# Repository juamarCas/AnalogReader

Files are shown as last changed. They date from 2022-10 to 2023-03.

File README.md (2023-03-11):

# Analog Reader
Circuit board based on STM303RBT6 microcontroller, made using Kicad v6

## Footage

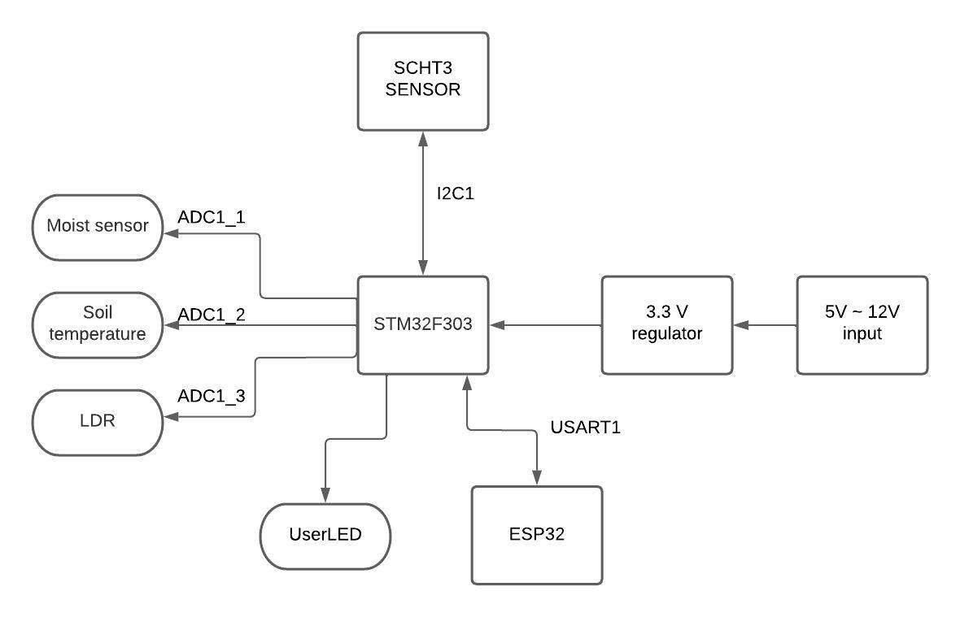
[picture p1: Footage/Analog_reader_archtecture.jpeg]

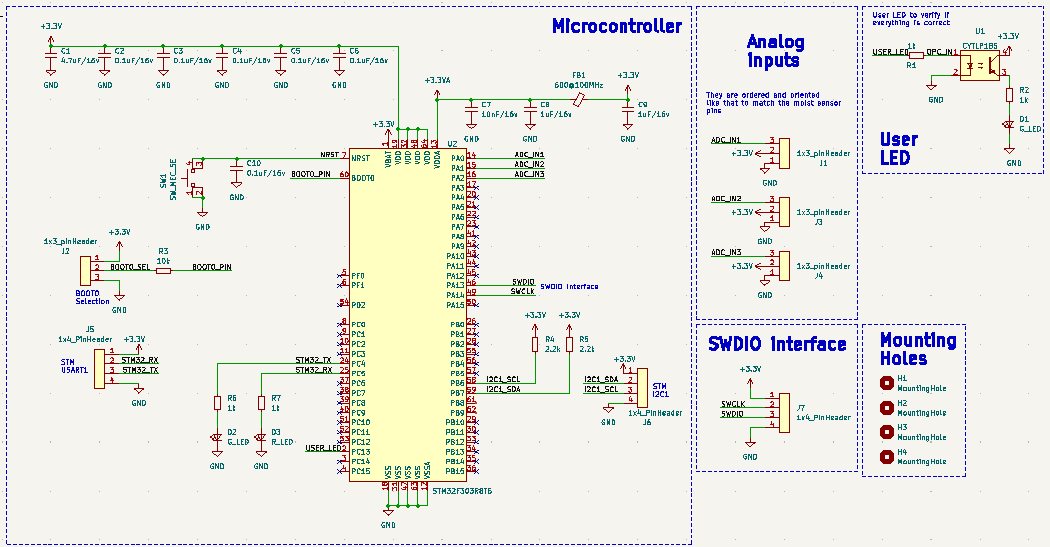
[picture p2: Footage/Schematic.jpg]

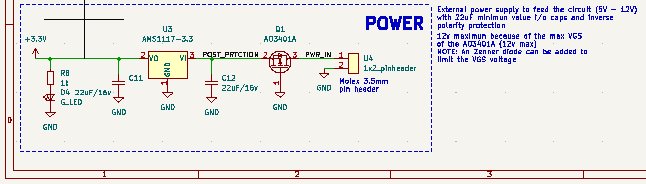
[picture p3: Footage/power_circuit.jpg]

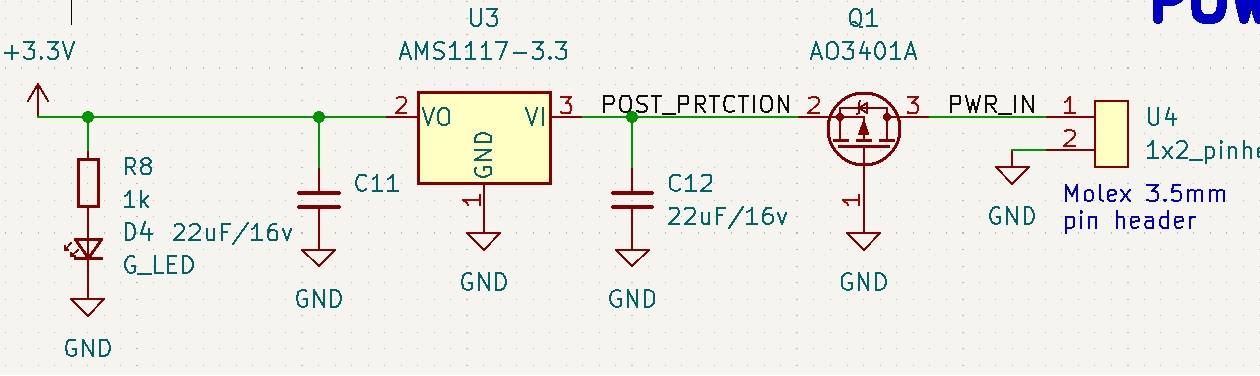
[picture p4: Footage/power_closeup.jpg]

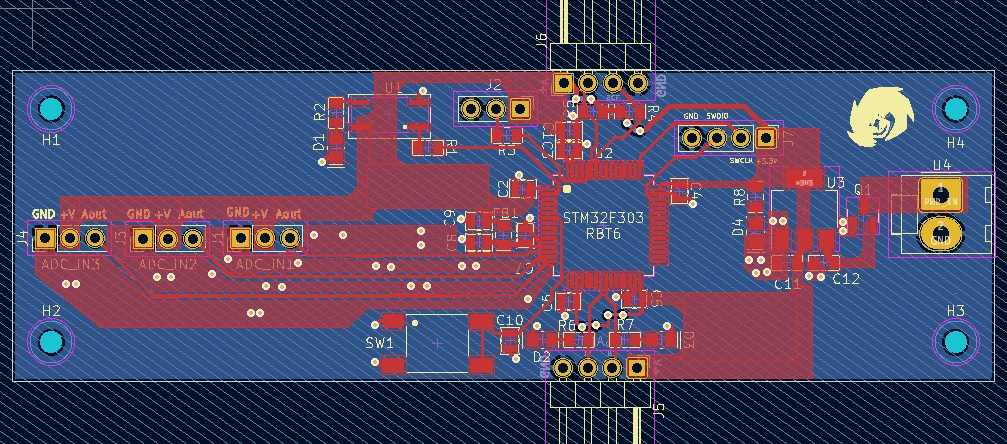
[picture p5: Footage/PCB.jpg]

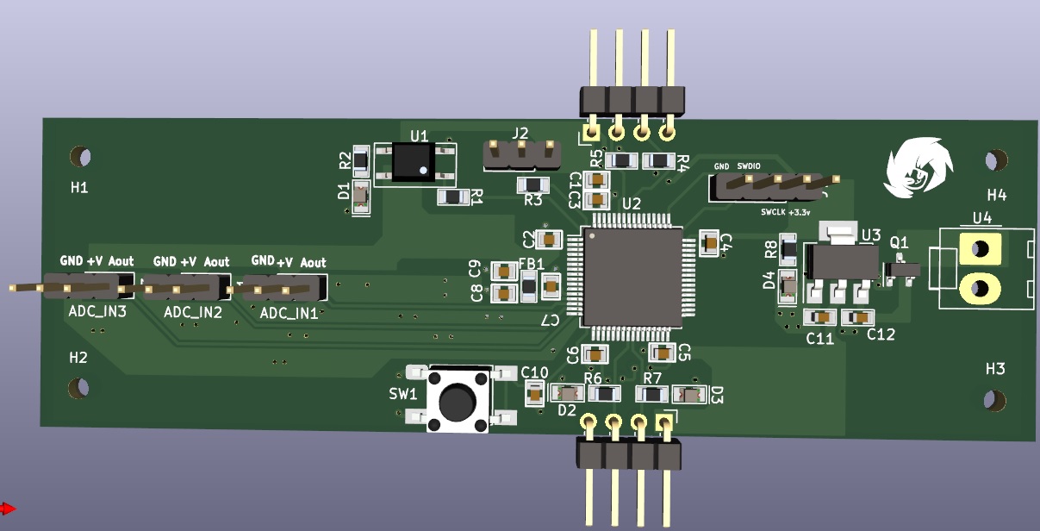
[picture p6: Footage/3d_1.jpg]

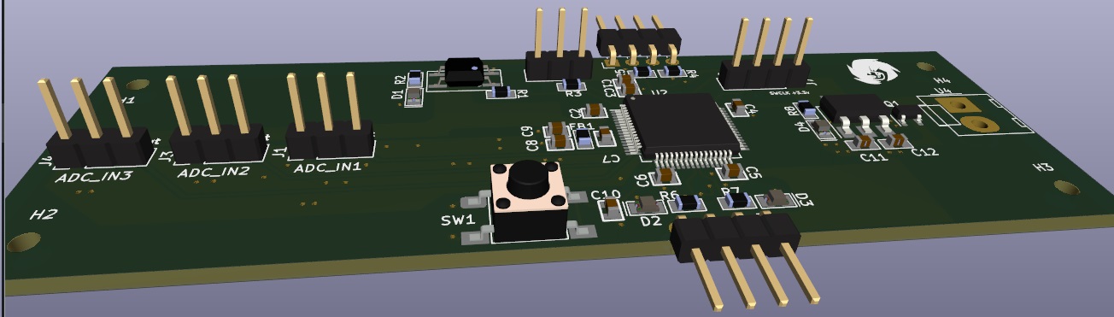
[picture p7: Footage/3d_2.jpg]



## Other parts of the project
* [MQTT Middleware](https://github.com/juamarCas/MQTT_middleware)
* [API REST](https://github.com/juamarCas/Sensor_API_REST)

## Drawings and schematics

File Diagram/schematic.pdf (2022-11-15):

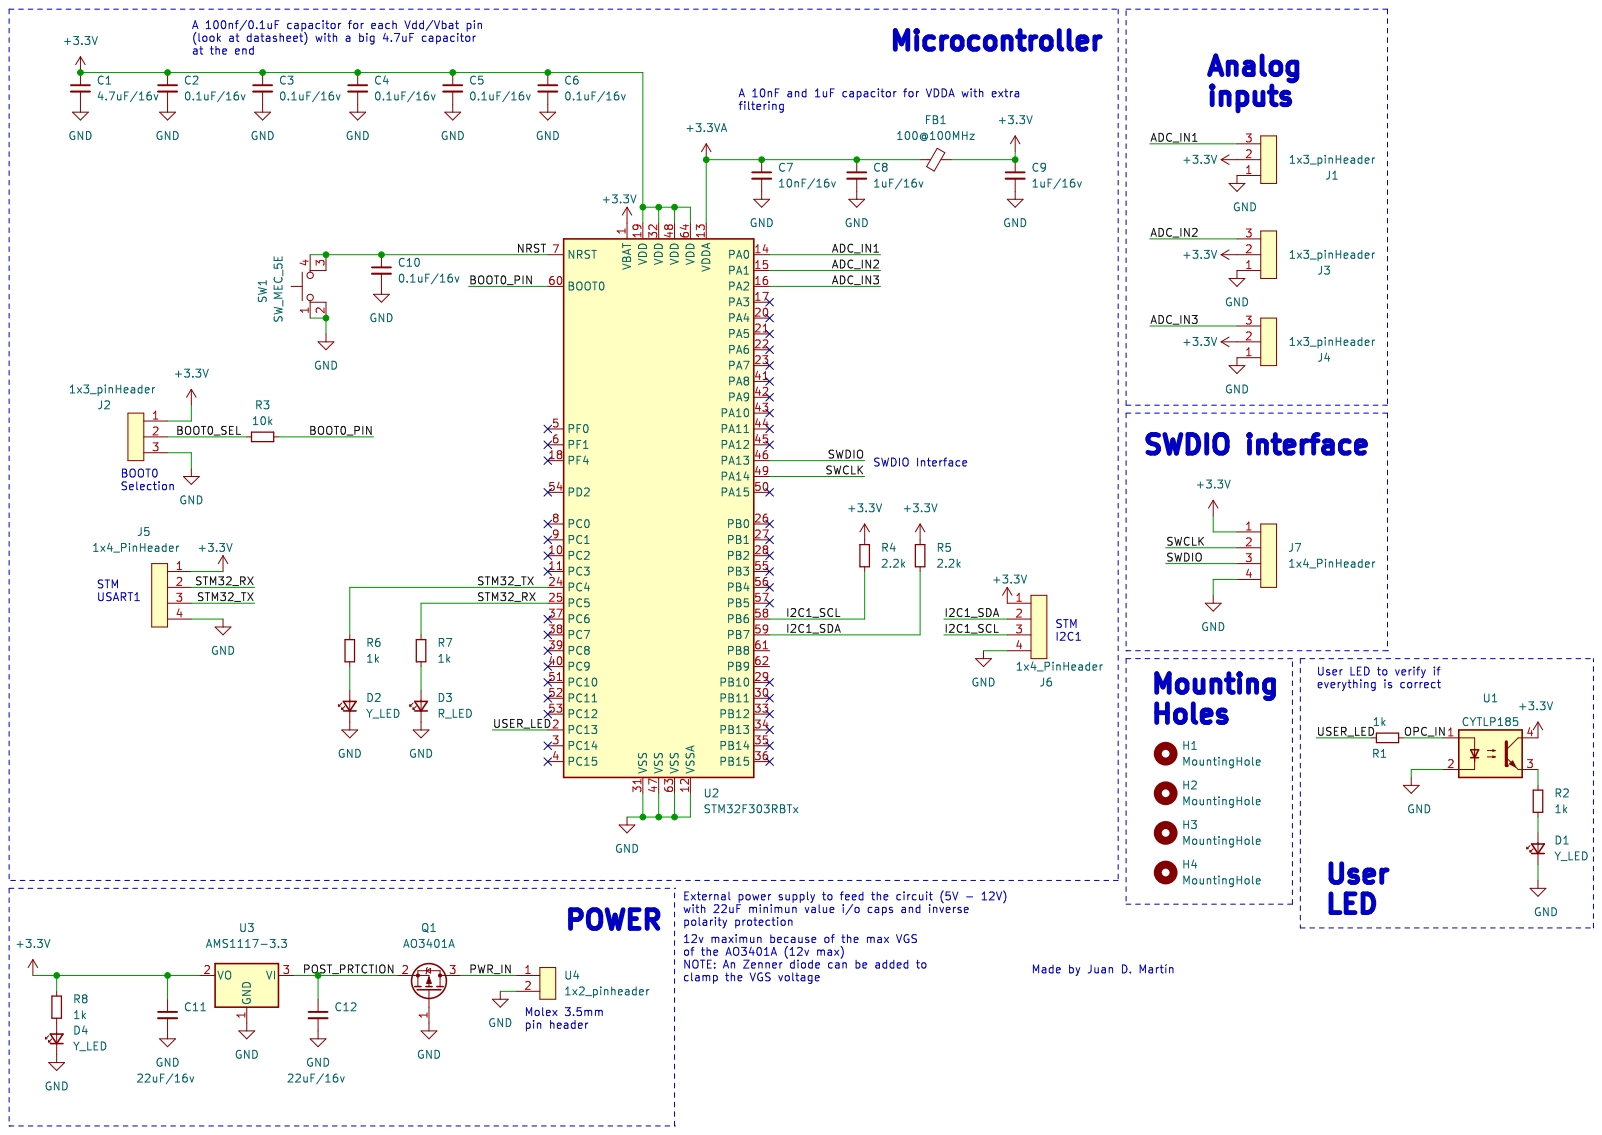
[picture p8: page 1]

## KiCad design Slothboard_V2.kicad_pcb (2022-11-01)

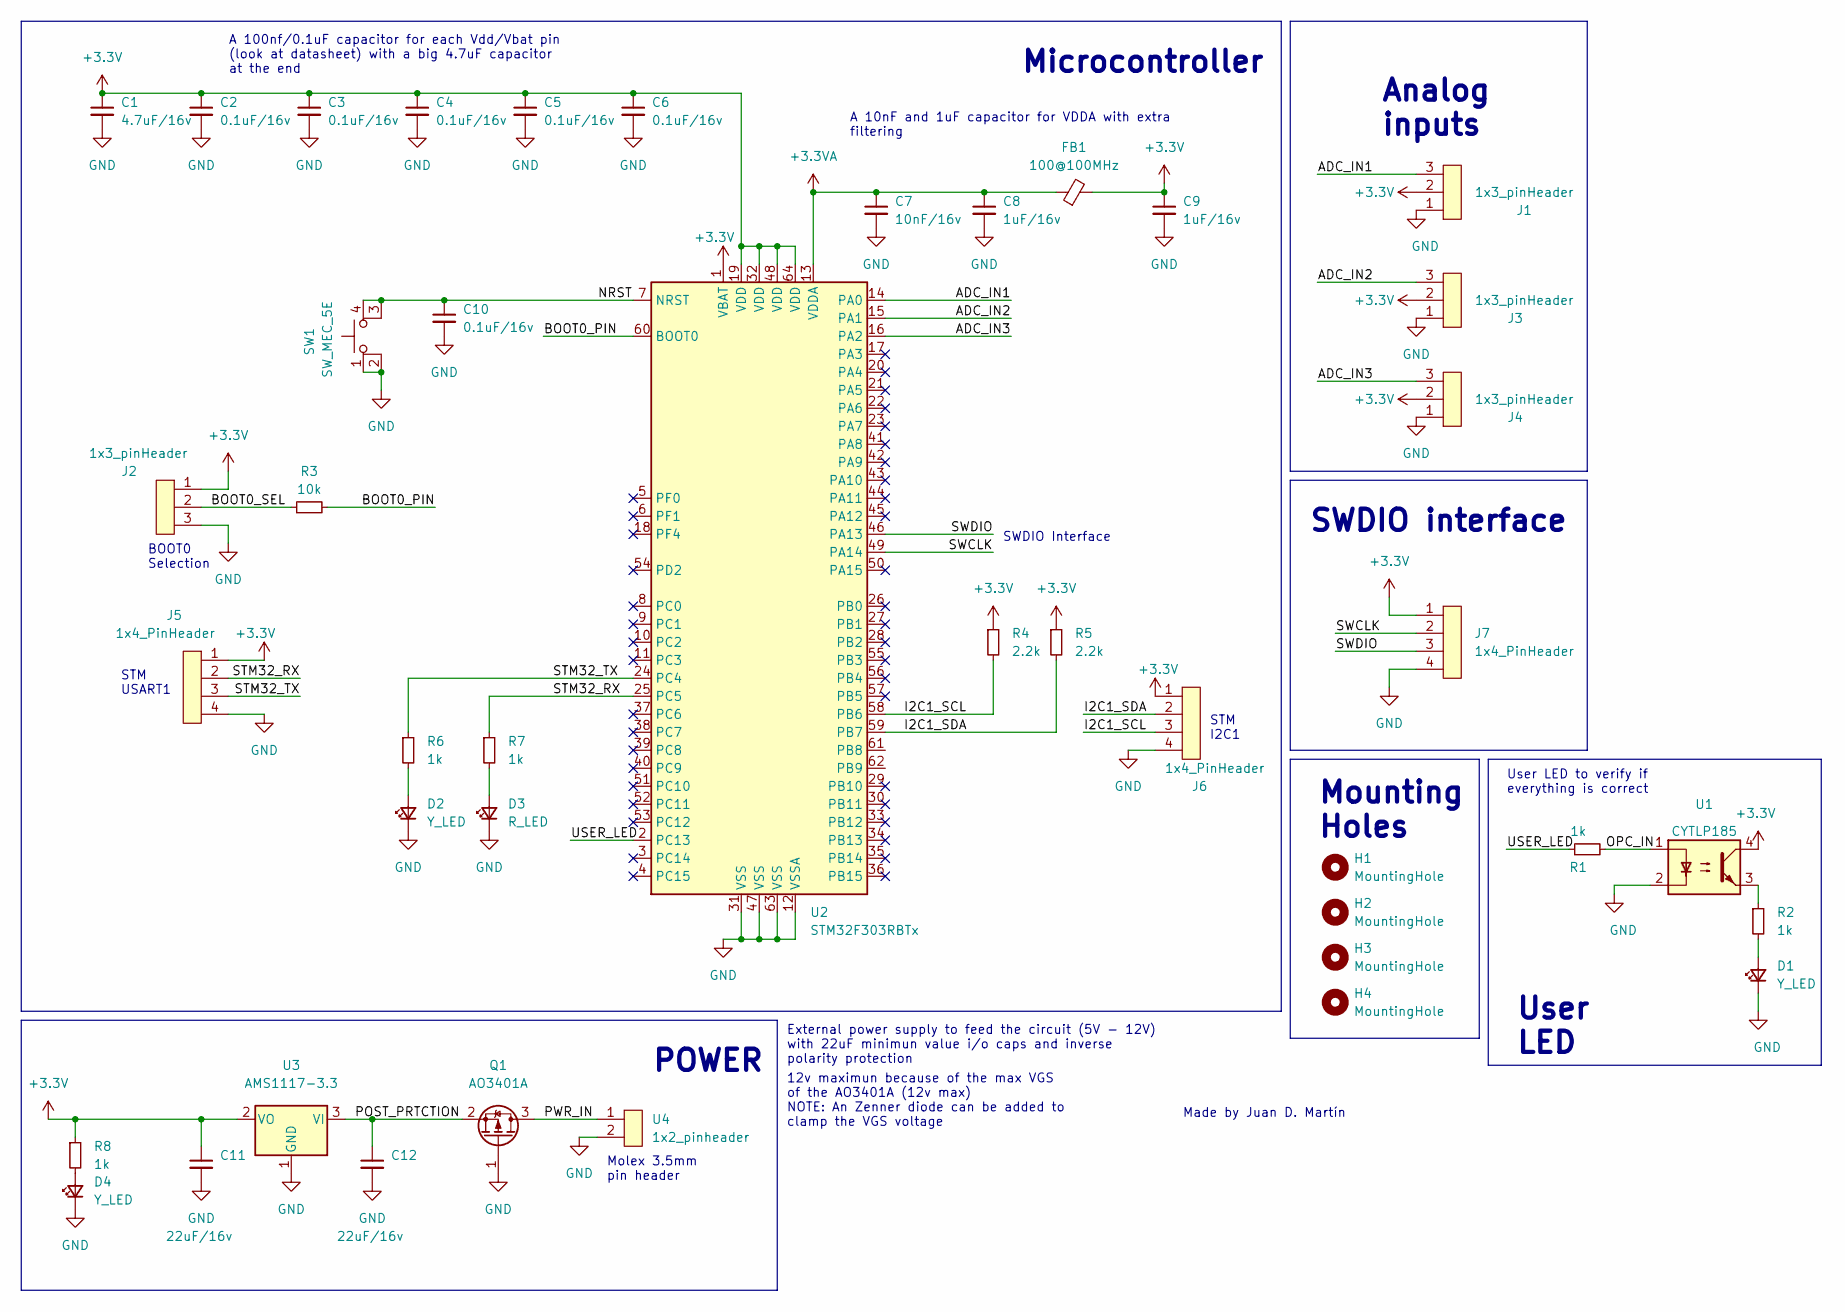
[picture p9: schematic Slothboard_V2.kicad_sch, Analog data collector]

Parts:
C1: 4.7uF/16v; 0603_Capacitor; LCSC Part # C19666
C2, C3, C4, C5, C6, C10: 0.1uF/16v; 0603_Capacitor; LCSC Part # C14663
C7: 10nF/16v; 0603_Capacitor; LCSC Part # C57112
C8, C9: 1uF/16v; 0603_Capacitor; JLCPCB Part # C15849
C11, C12: 22uF/16v; 0805_Capacitor; JLCPCB Part # C129303
D1, D2, D4: Y_LED; LED_0805; JLCPCB Part # C2296
D3: R_LED; LED_0805; JLCPCB Part # C84256
FB1: 100@100MHz; 0805_Resistor; JLCPCB Part # C1015
H1, H2, H3, H4: MountingHole; MountingHole_2.2mm_M2
J1, J2, J3, J4: 1x3_pinHeader; PinHeader_1x03_P2.54mm_Vertical
J5, J6: 1x4_PinHeader; PinHeader_1x04_P2.54mm_Horizontal
J7: 1x4_PinHeader; PinHeader_1x04_P2.54mm_Vertical
Q1: AO3401A; SOT-23; JLCPCB Part # C15127
R1, R2, R6, R7, R8: 1k; 0805_Resistor; JLCPCB Part # C17513
R3: 10k; 0805_Resistor; JLCPCB Part # C17414
R4, R5: 2.2k; 0805_Resistor; JLCPCB Part # C17520
SW1: SW_MEC_5E; PUSH_6x6mm_SMD
U1: CYTLP185; SOIC-4; JLCPCB Part # C385052
U2: STM32F303RBTx; LQFP-64_10x10mm_P0.5mm; JLCPCB Part # C130453
U3: AMS1117-3.3; SOT-223-3_TabPin2; JLCPCB Part # C6186
U4: 1x2_pinheader; Molex_KK-396_A-41791-0002_1x02_P3.96mm_Vertical

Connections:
+3.3VA: C7.1, C8.1, FB1.1, U2.13 (VDDA)
+3V3: C1.1, C2.1, C3.1, C4.1, C5.1, C6.1, C9.1, C11.1, FB1.2, J1.2, J2.1, J3.2, J4.2, J5.1, J6.1, J7.1, R4.1, R5.1, R8.1, U1.4, U2.1 (VBAT), U2.19 (VDD), U2.32 (VDD), U2.48 (VDD), U2.64 (VDD), U3.2 (VO)
/ADC_IN1: J1.3, U2.14 (PA0)
/ADC_IN2: J3.3, U2.15 (PA1)
/ADC_IN3: J4.3, U2.16 (PA2)
/BOOT0_PIN: R3.2, U2.60 (BOOT0)
/BOOT0_SEL: J2.2, R3.1
/I2C1_SCL: J6.3, R4.2, U2.58 (PB6)
/I2C1_SDA: J6.2, R5.2, U2.59 (PB7)
/NRST: C10.1, SW1.3 (K), SW1.4 (A), U2.7 (NRST)
/OPC_IN: R1.2, U1.1
/POST_PRTCTION: C12.1, Q1.2 (S), U3.3 (VI)
/PWR_IN: Q1.3 (D), U4.1
/STM32_RX: J5.2, R7.1, U2.25 (PC5)
/STM32_TX: J5.3, R6.1, U2.24 (PC4)
/SWCLK: J7.2, U2.49 (PA14)
/SWDIO: J7.3, U2.46 (PA13)
/USER_LED: R1.1, U2.2 (PC13)
GND: C1.2, C2.2, C3.2, C4.2, C5.2, C6.2, C7.2, C8.2, C9.2, C10.2, C11.2, C12.2, D1.1 (K), D2.1 (K), D3.1 (K), D4.1 (K), J1.1, J2.3, J3.1, J4.1, J5.4, J6.4, J7.4, Q1.1 (G), SW1.1, SW1.2, U1.2, U2.12 (VSSA), U2.31 (VSS), U2.47 (VSS), U2.63 (VSS), U3.1 (GND), U4.2
unnamed: D1.2 (A), R2.2
unnamed: D2.2 (A), R6.2
unnamed: D3.2 (A), R7.2
unnamed: D4.2 (A), R8.2
unnamed: R2.1, U1.3

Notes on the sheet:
User LED
Molex 3.5mm pin header
A 10nF and 1uF capacitor for VDDA with extra filtering
A 100nf/0.1uF capacitor for each Vdd/Vbat pin (look at datasheet) with a big 4.7uF capacitor at the end
STM USART1
BOOT0 Selection
POWER
Mounting Holes
SWDIO interface
External power supply to feed the circuit (5V - 12V) with 22uF minimun value i/o caps and inverse polarity protection
SWDIO Interface
12v maximun because of the max VGS of the AO3401A (12v max) NOTE: An Zenner diode can be added to clamp the VGS voltage
User LED to verify if everything is correct
Microcontroller
STM I2C1
Made by Juan D. Martín
Analog inputs

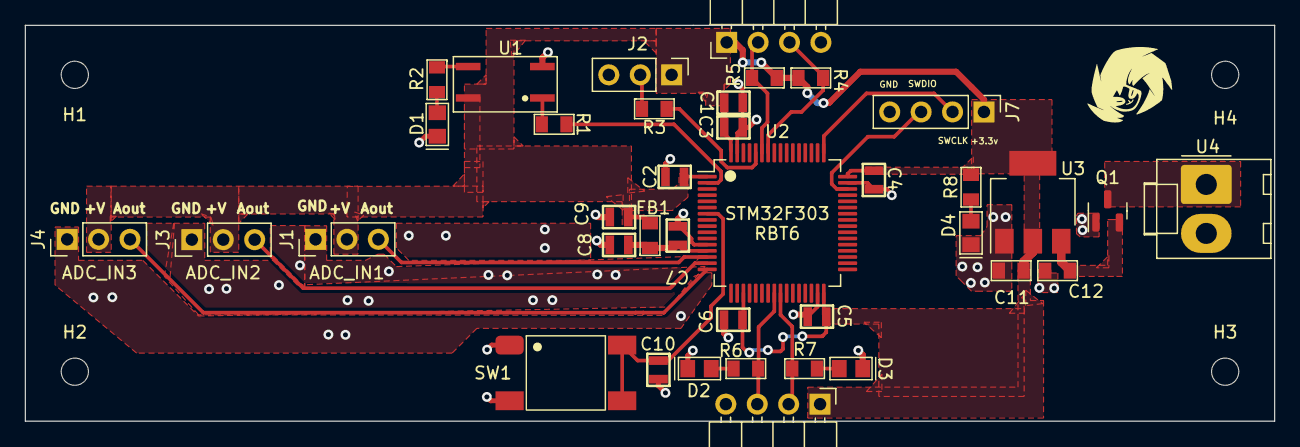
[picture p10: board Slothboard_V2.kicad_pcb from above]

Board: 2 copper layers, 101.0 x 32.0 mm, 42 parts (0 on the bottom side), 24 nets.

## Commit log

2022-10-10 finished 0.1v
    [Slothboard_V2.kicad_pcb, Slothboard_V2.kicad_sch]
2022-11-01 added more photos
    [Slothboard_V2.kicad_pcb, Slothboard_V2.kicad_sch]
